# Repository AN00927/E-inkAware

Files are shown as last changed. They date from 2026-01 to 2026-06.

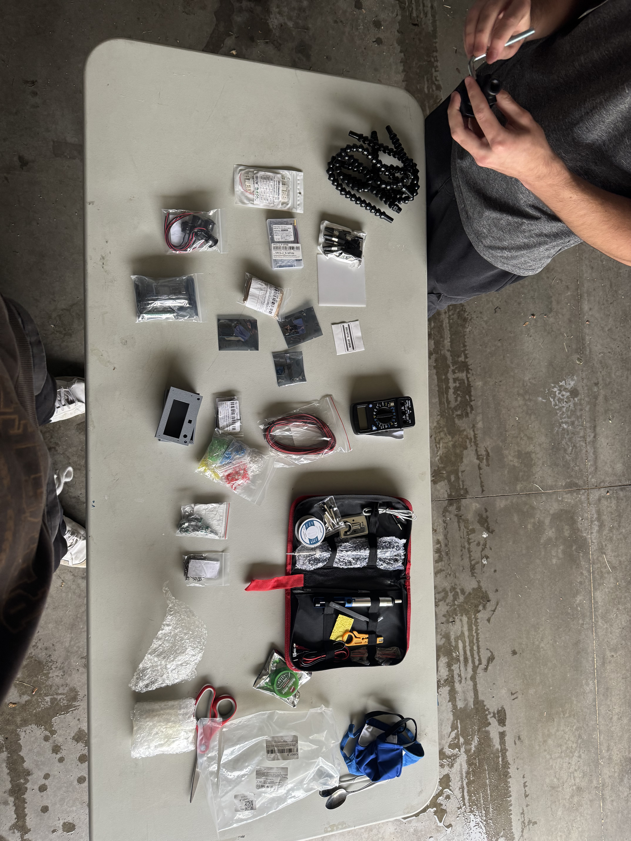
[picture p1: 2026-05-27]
Physical Progress Photos/MaterialsUnpacked.jpeg

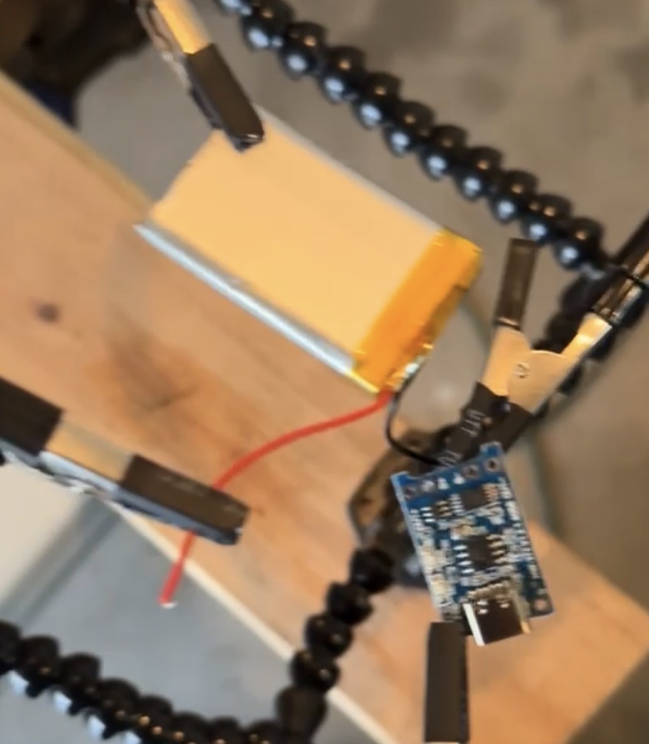
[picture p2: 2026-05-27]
Physical Progress Photos/InitialSolder.jpg

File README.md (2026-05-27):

# E-inkAware
I am creating a E-ink display that takes note of the light level around it to determine whether to turn on a reading light! The device is portable and will be display things like the time, calendar, and hopefully more complex things like real-time reminders. Progress is documented and explained at [HackClub](https://blueprint.hackclub.com/projects/8115)

In order to use it, you turn it on with the switch on the side. The display will show the current time and calendar. It will turn on the screen backlight based on the light level it senses. Use the rotary encoder to go between different pages! The pages are Dashboard, Notes, Note Viewer, and System info.
To add notes, long press the encoder button to turn on Bluetooth. Then connect to "EInk_Companion" from your phone or computer and send a message formatted as NOTE: "whatever note you have". Short press the encoder to open a note or toggle the frontlight manually. If you leave it alone for 30 minutes it'll go to sleep on its own. To wake it up press the encoder. It is charged by USB-C

A friend of mine and I made this project because we honestly thought it would be really cool to try to create our first project with a screen, since our previous projects have mostly been things that mankind could have made anytime in the last millenia (dehydrator)
We also wanted to expirement with light sensors since they are one of the cheapest yet most effective sensors
We will also make this over a 1-2 month period, and we'll make sure to document all of our progress.
We did not design a custom PCB. 
This design was reviewed by Justin Blevins.

In order to connect the electrical components, we will solder wires.

## Render
E-ink 3D Render

## Schematic
Schematic
" />

## Bill of Materials
| Product Name | Description | Project usage | Unit Price | Quantity | Total | Link |
|---|---|---|---|---|---|---|
| 2.9” SPI E-Ink Display | Low-power monochrome e-ink display using SPI | Displays persistent info; power only on refresh and/or partial refresh | $10.95 | 1 | $10.95 | https://www.aliexpress.us/item/3256804458201128.html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 |
| ESP32 DevKit / ESP32-WROOM-32 | 32-bit microcontroller | Main controller for display, sensors, power, and sleep | $6.03 | 1 | $6.03 | https://a.aliexpress.com/_mP8xeeh |
| BH1750 Ambient Light Sensor | Digital I²C light sensor | Auto front - light enable/adjust | $1.55 | 1 | $1.55 | https://a.aliexpress.com/_m0emckz |
| EC11 Rotary Encoder | Mechanical encoder + button | User input / navigation | $3.20 | 1 | $3.20 | https://a.aliexpress.com/_mMVUzI9 |
| White LEDs | Discrete white LEDs (2), voltage = 1.8, 3mm | Front-lighting in low light | $2.66 | 1 | $2.66 | https://a.aliexpress.com/_mP2d4oz |
| Logic-Level N-MOSFET (AO3400) | Low-side switch | PWM LED brightness control | $1.60 | 1 | $1.60 | https://a.aliexpress.com/_msAeC4N |
| Resistors (assorted) | 100kΩ | LED current limiting / tuning, and voltage divider for battery | $2.74 | 2 | $5.48 | https://a.aliexpress.com/_mK8bSHP |
| 1.4mm Frosted Acrylic / PET | Diffusing sheet | Even light spread | $4.04 | 1 | $4.04 | https://a.aliexpress.com/_mMZ5c1P |
| Li-Po Battery | 3.7V rechargeable battery 2 count, 1000mAh | Primary power storage | $5.24 | 1 | $5.24 | https://a.aliexpress.com/_msZFe1j |
| TP4056 Charging Module | Li-Po charger + protection | Safe charging | $6.07 | 1 | $6.07 | https://a.aliexpress.com/_mqVssZB |
| Wires (22 AWG, 5M) | Insulated copper wire | Interconnections | $3.05 | 1 | $3.05 | https://a.aliexpress.com/_msOwZ8D |
| Slide switch | Mechanical on/off switch | Hard power cutoff | $3.17 | 1 | $3.17 | https://www.aliexpress.us/item/3256806912505731.html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 |
| M2.6 Self-tapping Screws | Metric fasteners | Secure PCB & enclosure | $1.66 | 1 | $1.66 | https://www.aliexpress.us/item/2255800795894953.html |
| Decoupling Capacitors | 100nF cermaic decoupling  (805) | Power stabilization near the ESP32 and Display | $3.40 | 1 | $3.40 | https://a.aliexpress.com/_msBwDKz |

Subtotal: $54.70

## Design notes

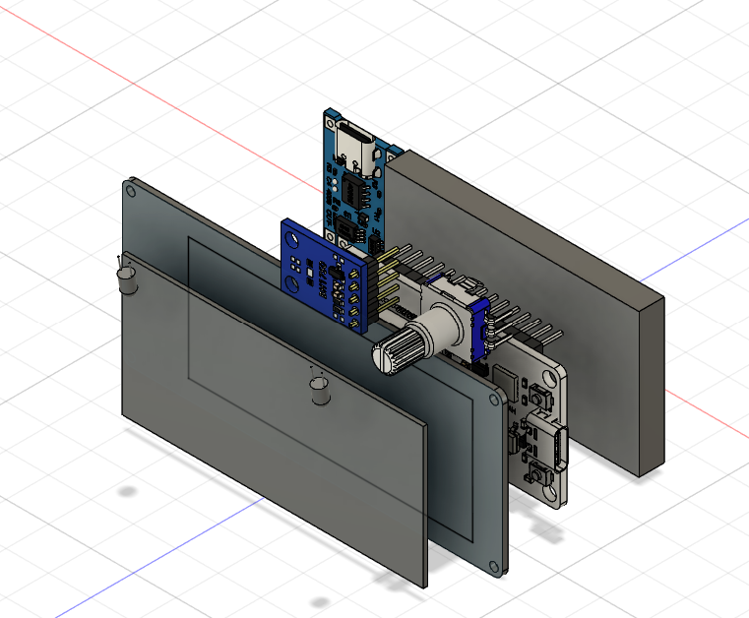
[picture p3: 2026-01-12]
Design Progress Photos/Screenshot 2025-12-28 181926.png

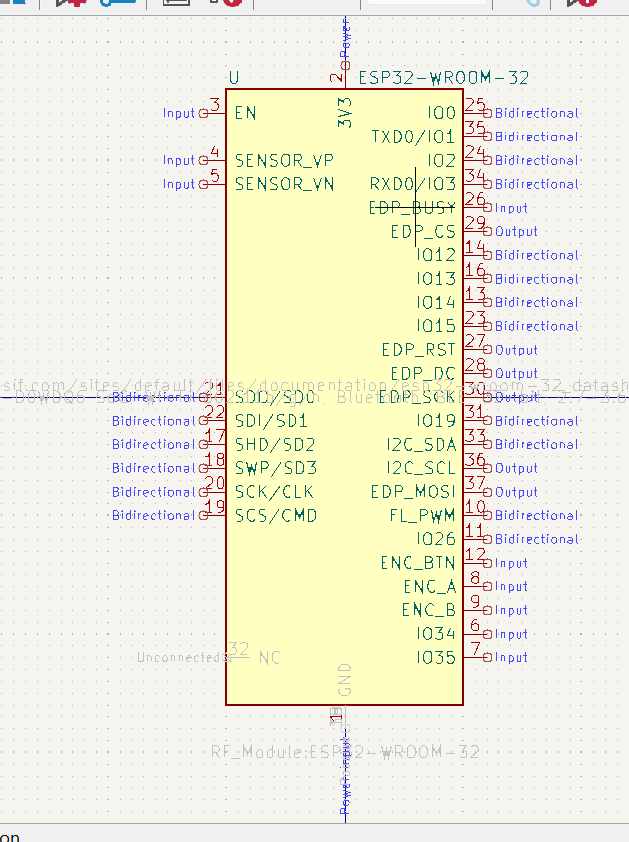
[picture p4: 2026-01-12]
Design Progress Photos/Screenshot 2026-01-08 215834.png

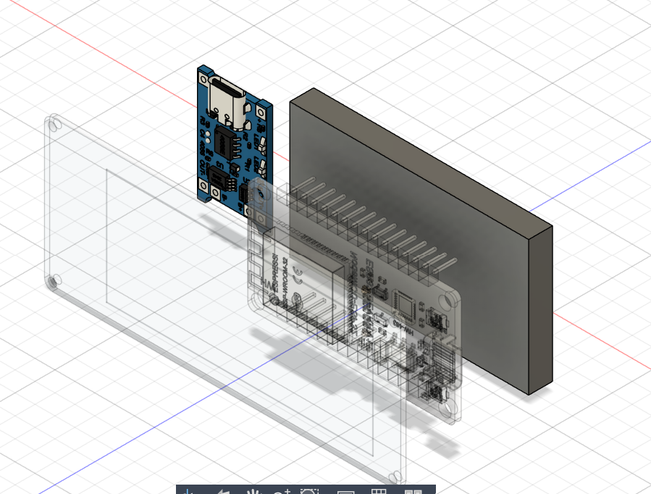
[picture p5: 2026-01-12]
Design Progress Photos/Screenshot 2025-12-28 150306.png

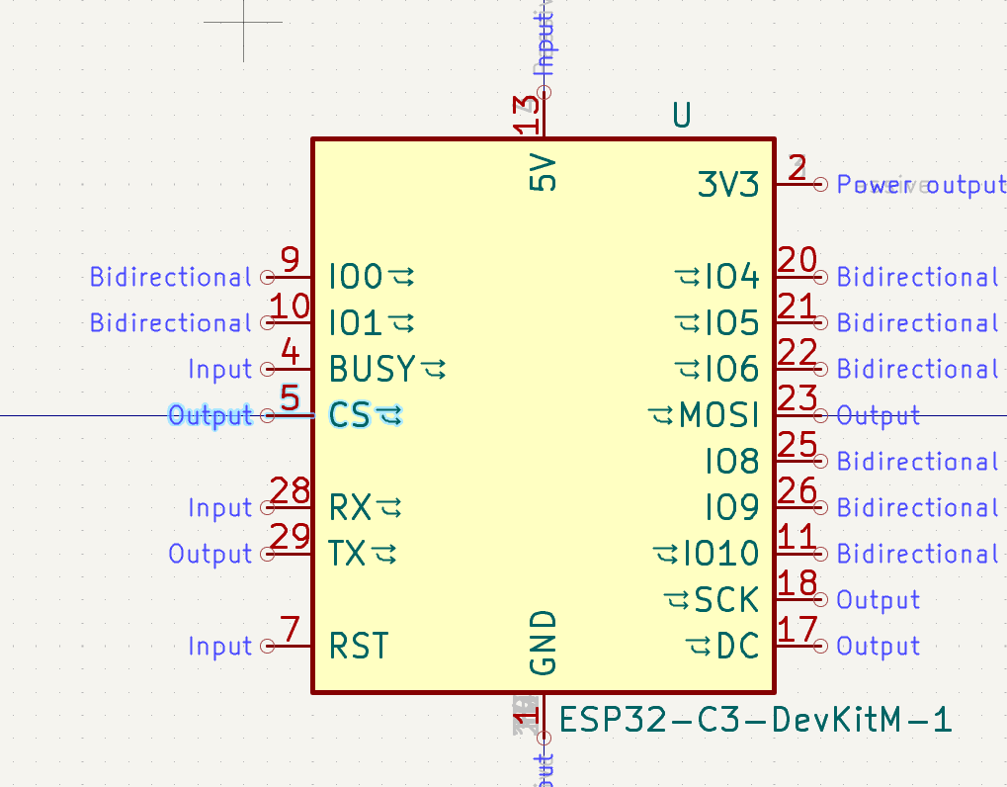
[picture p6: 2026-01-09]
Design Progress Photos/Screenshot 2026-01-07 214725.png

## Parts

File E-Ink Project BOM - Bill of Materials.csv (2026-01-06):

Product Name | Description | Project usage | Unit Price | Quantityy | Total | Link
2.9” SPI E-Ink Display | Low-power monochrome e-ink display using SPI | Displays persistent info; power only on refresh and/or partial refresh | $11.22 | 1 | $11.22 | https://a.aliexpress.com/_msPID7J
ESP32 DevKit / ESP32-WROOM-32 | 32-bit microcontroller | Main controller for display, sensors, power, and sleep | $6.24 | 1 | $6.24 | https://a.aliexpress.com/_mP8xeeh
BH1750 Ambient Light Sensor | Digital I²C light sensor | Auto front - light enable/adjust | $2.39 | 1 | $2.39 | https://a.aliexpress.com/_m0emckz
EC11 Rotary Encoder | Mechanical encoder + button | User input / navigation | $3.27 | 1 | $3.27 | https://a.aliexpress.com/_mMVUzI9
White LEDs | Discrete white LEDs | Front-lighting in low light | $2.71 | 1 | $2.71 | https://a.aliexpress.com/_mP2d4oz
Logic-Level N-MOSFET (AO3400) | Low-side switch | PWM LED brightness control | $1.64 | 1 | $1.64 | https://a.aliexpress.com/_msAeC4N
Resistors (assorted) | Fixed-value resistors | LED current limiting / tuning | $2.70 | 2 | $5.40 | https://a.aliexpress.com/_mK8bSHP
1.4mm Frosted Acrylic / PET | Diffusing sheet | Even light spread | $4.44 | 1 | $4.44 | https://a.aliexpress.com/_mMZ5c1P
Li-Po Battery | 3.7V rechargeable battery | Primary power storage | $4.51 | 1 | $4.51 | https://a.aliexpress.com/_mKdA6tn
TP4056 Charging Module | Li-Po charger + protection | Safe charging | $6.47 | 1 | $6.47 | https://a.aliexpress.com/_mqVssZB
Wires (22 AWG) | Insulated copper wire | Interconnections | $3.08 | 1 | $3.08 | https://a.aliexpress.com/_msOwZ8D
Slide switch | Mechanical on/off switch | Hard power cutoff | $2.81 | 1 | $2.81 | https://www.aliexpress.us/item/3256806912505731.html?curPageLogUid=DC3gG5h1SoYY
Custom 3D-Printed Enclosure | CAD-designed encolsure | Physical protection & layout | $5.00 | 1 | $5.00 | I will print
M2.5 Self-tapping Screws | Metric fasteners | Secure PCB & enclosure | $1.76 | 1 | $1.76 | https://www.aliexpress.us/item/2255800795894953.html
 |  |  |  | Subtotal | $64.25
 |  |  |  | Discount | $50.23
 | Contingency (price changes / flawed parts) |  |  | 15% | $57.76

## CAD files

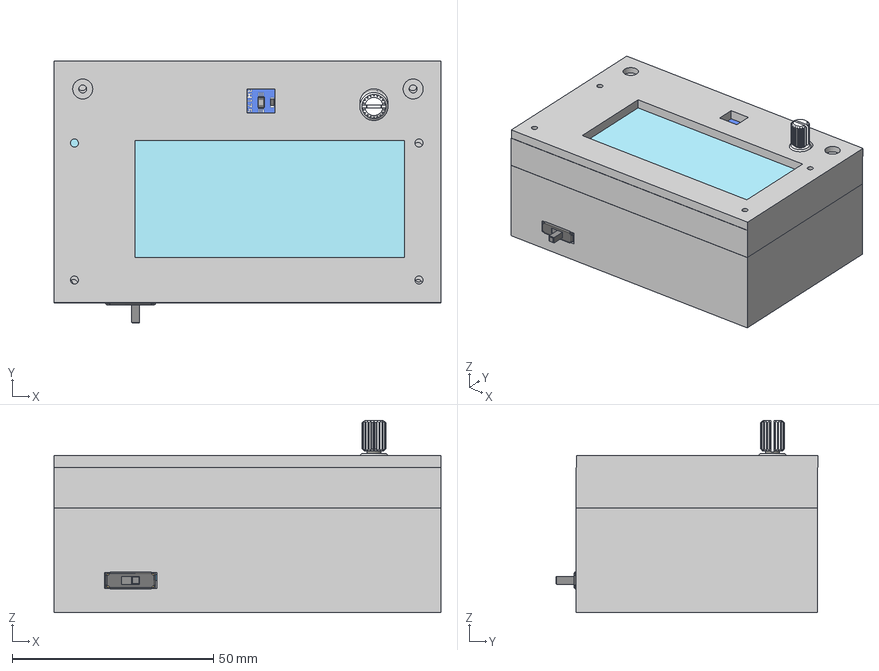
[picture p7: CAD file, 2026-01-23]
CAD Files/E-ink project STEP File.step
96.0 x 65.1 x 47.7 mm
E-ink display
rotary Encoder
LED1
LED2
Diffuser
Light Sensor
LiPo Battery
ESP32
Slide Switch
MOSFET (AO3400, not A1SHB)
TP4056

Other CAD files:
CAD Files/E-ink project.f3z

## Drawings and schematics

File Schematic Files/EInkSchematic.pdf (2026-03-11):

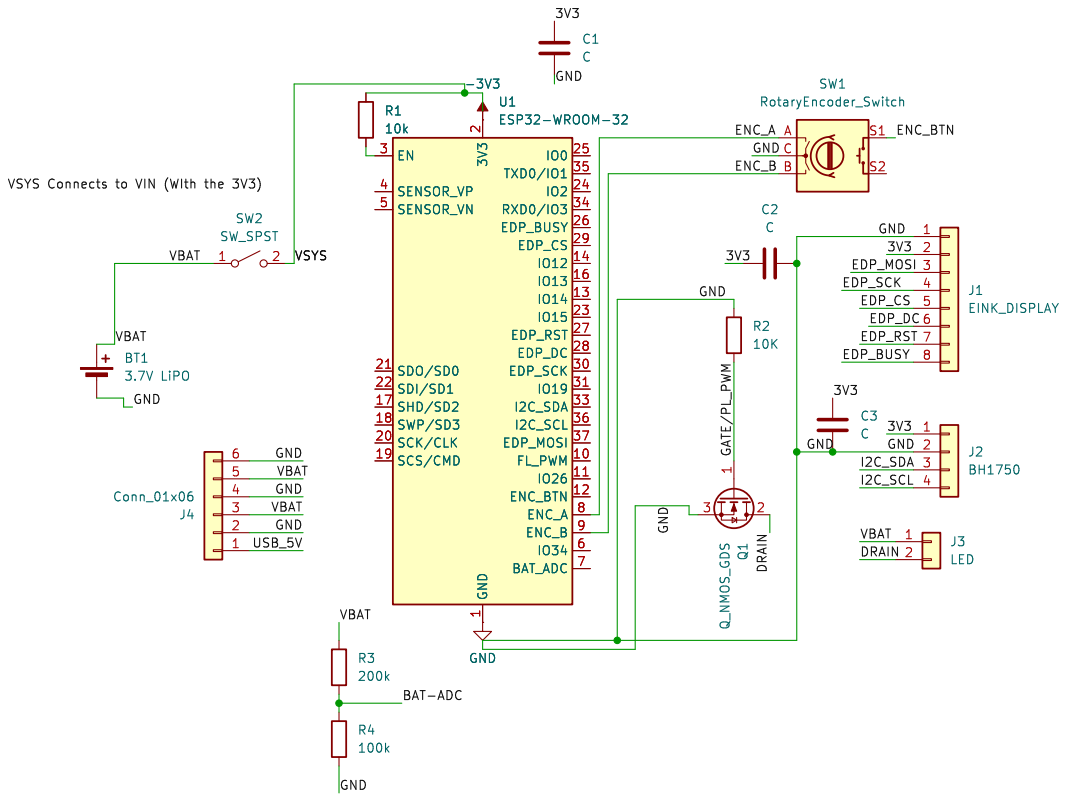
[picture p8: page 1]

Id: 1/1 Title: File: light-aware-eink.kicad_sch Sheet: /

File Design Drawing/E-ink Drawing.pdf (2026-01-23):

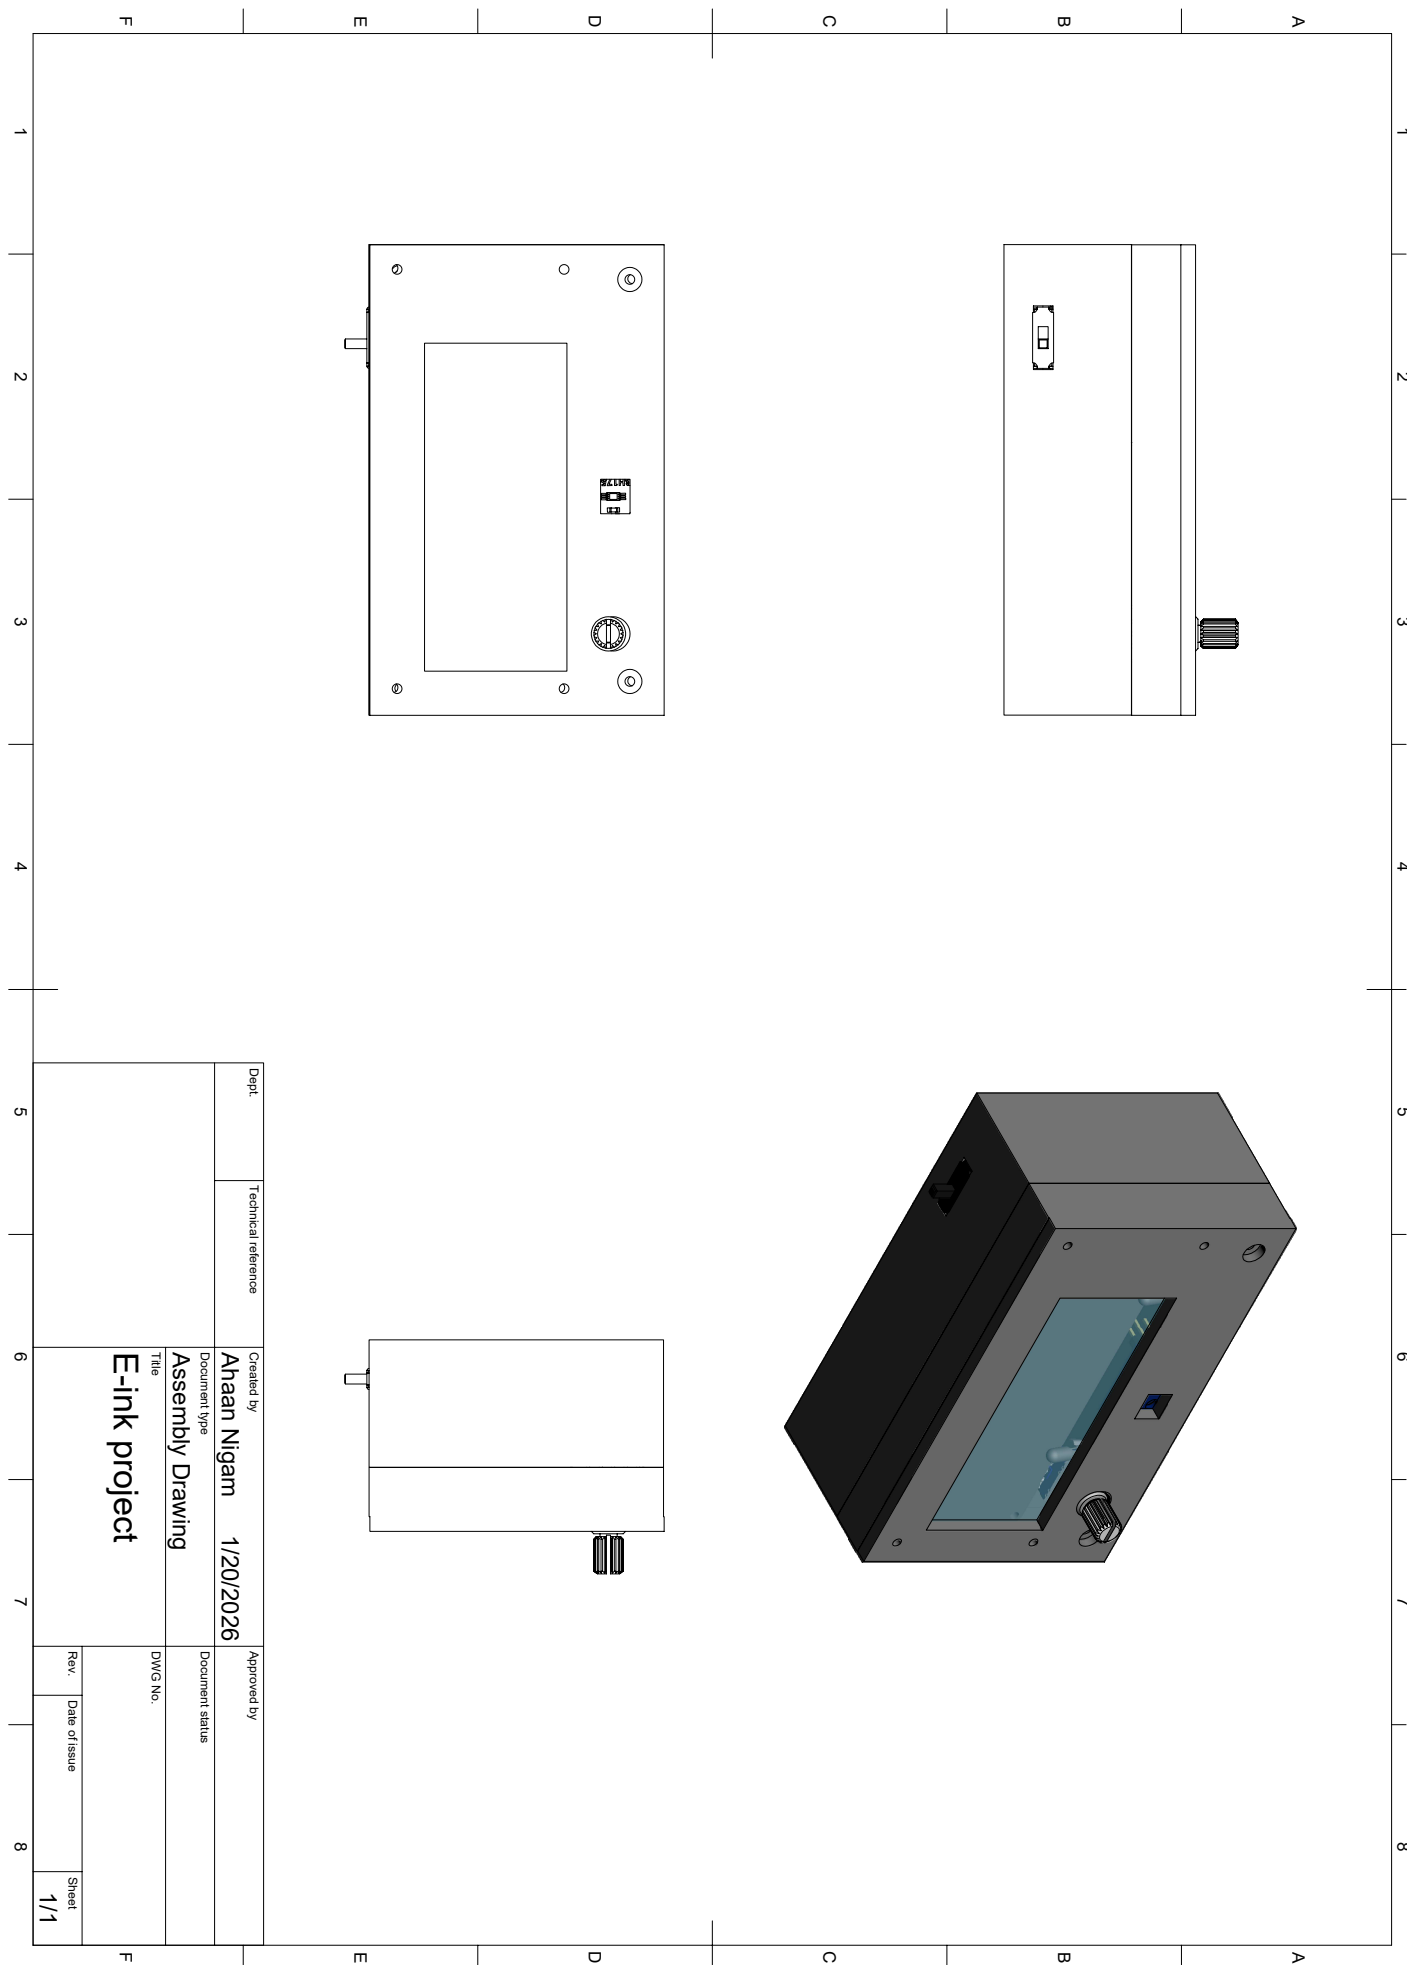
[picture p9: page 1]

1 A 2 3 4 5 6 7 8 1 2 3 4 5 6 7 8 FEDCB FEDCBA Dept. Technical reference Created by Approved by Title DWG No. Document type Document status Rev. Date of issue Sheet Assembly Drawing1/20/2026 1/1 E-ink project Ahaan Nigam

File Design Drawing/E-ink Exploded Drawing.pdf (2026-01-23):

29.05 66.89

# 13 ⁸⁷.45

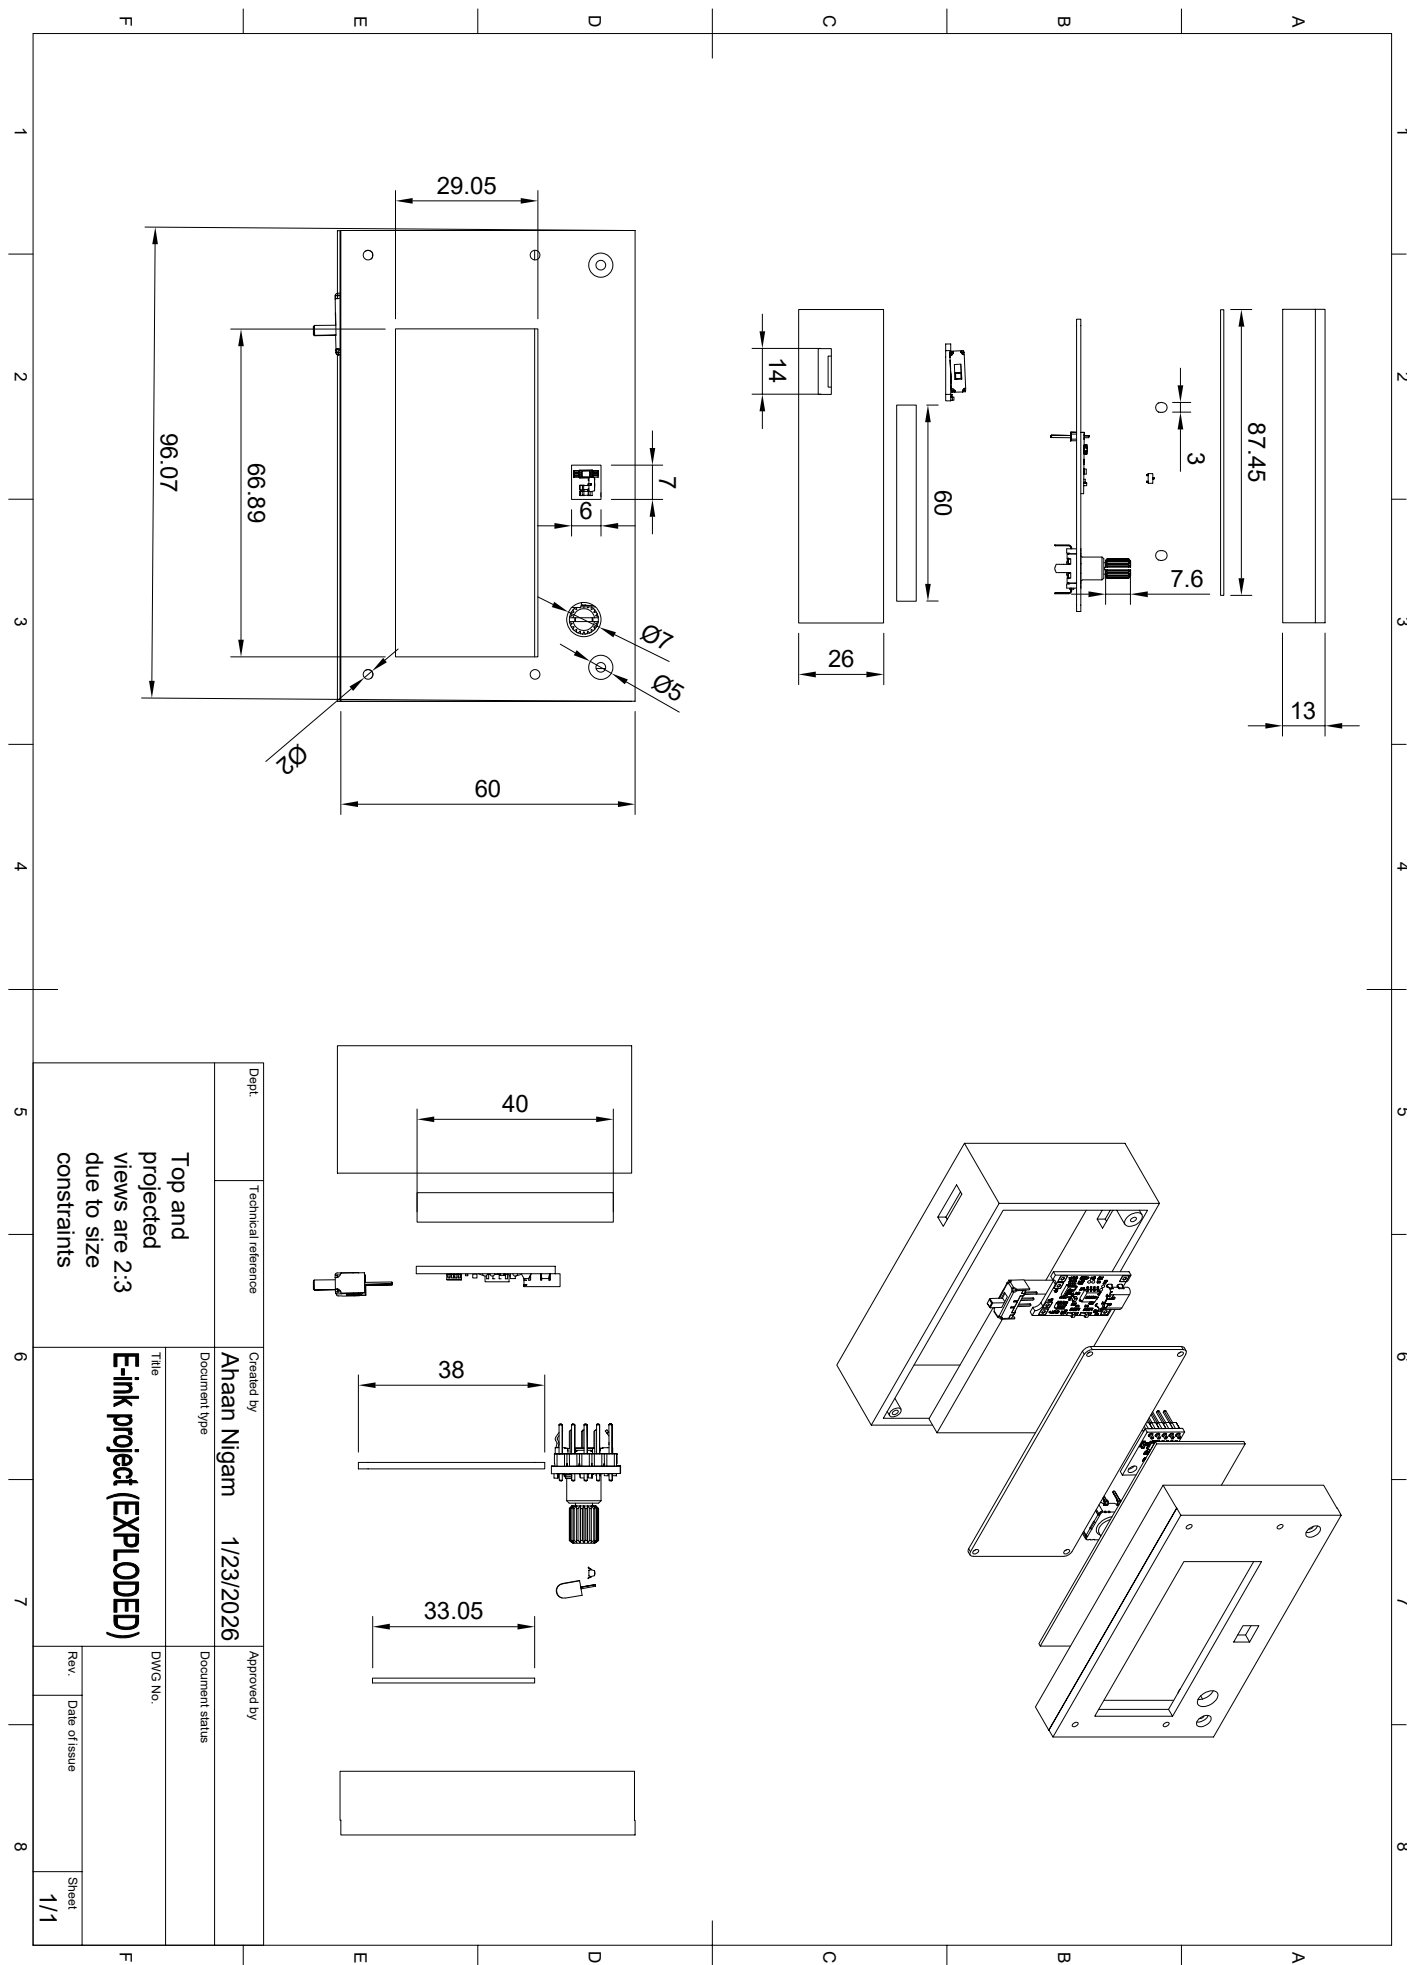
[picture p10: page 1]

1 A 2 3 4 5 6 7 8 1 2 3 4 5 6 7 8 FEDCB FEDCBA Dept. Technical reference Created by Approved by Title DWG No. Document type Document status Rev. Date of issue Sheet 1/23/2026 1/1 Ahaan Nigam constraints due to size views are 2:3 projected Top and 96.07

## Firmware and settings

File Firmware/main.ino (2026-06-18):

/*
  E-inkAware — WeAct 2.9" B/W (GxEPD2_BW)
  Fixed for ESP32 Arduino core 3.x
*/

#include <Arduino.h>
#include <Wire.h>
#include <Preferences.h>
#include <WiFi.h>
#include <time.h>

#include <FS.h>
#include <LittleFS.h>
#include <ArduinoOTA.h>

#include <BLEDevice.h>
#include <BLEUtils.h>
#include <BLEServer.h>
#include <BLE2902.h>

#include <BH1750.h>

#include <GxEPD2_BW.h>
#include <Adafruit_GFX.h>
#include <Fonts/FreeMonoBold9pt7b.h>

// ========== CONFIG ==========
#define EPD_CS   5
#define EPD_DC   17
#define EPD_RST  16
#define EPD_BUSY 4
#define EPD_SCK  18
#define EPD_MOSI 23

#define ENC_A_PIN     14
#define ENC_B_PIN     27
#define ENC_BTN_PIN   33

#define I2C_SDA       21
#define I2C_SCL       22

#define LED_PWM_PIN   25
// FIX: core 3.x uses pin-based LEDC, no channel needed
#define LEDC_FREQ     5000
#define LEDC_RES      8

#define BAT_ADC_PIN   35
const float DIVIDER_FACTOR = 3.0f;
const float BAT_EMPTY_V = 3.0f;
const float BAT_FULL_V  = 4.2f;

const uint32_t INACTIVITY_MIN = 30;

#define SERVICE_UUID   "e1230001-1234-5678-1234-56789abcdef0"
#define CHAR_TEXT_UUID "e1230002-1234-5678-1234-56789abcdef0"

static const char *PREF_NS         = "einkapp";
static const char *DEVICE_NAME     = "EInk_Companion";
static const int   MAX_NOTES       = 128;
static const int   NOTES_PER_PAGE  = 6;
static const int   NOTE_CHARS_PER_LINE = 38;
static const int   NOTE_VISIBLE_LINES  = 6;
static const char *NOTES_DIR       = "/notes";
static const char *NOTE_SEQ_KEY    = "note_seq";
static const char *WIFI_SSID_KEY   = "ssid";
static const char *WIFI_PASS_KEY   = "pass";
static const char *LIGHT_MODE_KEY  = "light_mode";

enum PageMode : uint8_t {
  PAGE_DASHBOARD = 0,
  PAGE_NOTES     = 1,
  PAGE_NOTE_VIEW = 2,
  PAGE_SYSTEM    = 3,
  PAGE_OTA       = 4,
};

enum LightMode : uint8_t {
  LIGHT_MODE_AUTO       = 0,
  LIGHT_MODE_FORCED_ON  = 1,
  LIGHT_MODE_FORCED_OFF = 2,
};

GxEPD2_BW<GxEPD2_290_BS, GxEPD2_290_BS::HEIGHT> display(
  GxEPD2_290_BS(EPD_CS, EPD_DC, EPD_RST, EPD_BUSY));

BH1750     lightMeter;
Preferences prefs;

// BLE
BLEServer         *bleServer   = nullptr;
BLECharacteristic *textChar    = nullptr;
bool               bleEnabled  = false;
unsigned long      bleEnableTs = 0;
const unsigned long BLE_ENABLE_TIMEOUT_MS = 2UL * 60UL * 1000UL;

// WiFi / OTA
bool          wifiConnected = false;
bool          otaActive     = false;
unsigned long otaStartTs    = 0;
const unsigned long OTA_ENABLE_TIMEOUT_MS = 20UL * 60UL * 1000UL;

// UI
PageMode currentPage       = PAGE_DASHBOARD;
int      selectedNoteIndex = 0;
int      noteViewIndex     = 0;
int      notesPageOffset   = 0;
int      noteScrollLine    = 0;


// Encoder
static portMUX_TYPE encoderMux = portMUX_INITIALIZER_UNLOCKED;  // ADD THIS
volatile int32_t encoderDelta     = 0;
volatile uint8_t encoderLastState = 0;
int32_t          encoderAccum     = 0;

// Front-light
const float LUX_THRESHOLD_ON  = 40.0f;
const float LUX_THRESHOLD_OFF = 55.0f;
const int   LIGHT_PWM_ON      = 200;
const int   LIGHT_PWM_MIN     = 0;
LightMode   lightMode         = LIGHT_MODE_AUTO;
bool        frontLightOn      = false;
unsigned long lastLightSampleMs = 0;

// Notes index
String   noteFiles[MAX_NOTES];
int      noteCount    = 0;
uint32_t nextNoteSeq  = 1;
bool     filesystemReady = false;

// Timing
unsigned long lastActivityMs         = 0;
unsigned long lastDashboardRefreshMs = 0;
unsigned long lastSystemRefreshMs    = 0;
unsigned long lastOtaRefreshMs       = 0;

// ========== HELPERS ==========
int batteryPercentFromVoltage(float v) {
  if (v <= BAT_EMPTY_V) return 0;
  if (v >= BAT_FULL_V)  return 100;
  return (int)round((v - BAT_EMPTY_V) / (BAT_FULL_V - BAT_EMPTY_V) * 100.0f);
}

float readBatteryVoltage() {
  uint16_t raw = analogRead(BAT_ADC_PIN);
  return (raw / 4095.0f) * 3.3f * DIVIDER_FACTOR;
}

String normalizeNoteText(String text) {
  text.replace("\r", " ");
  text.replace("\n", " ");
  text.replace("\t", " ");
  text.trim();
  return text;
}

String notePathForSeq(uint32_t seq) {
  char path[48];
  snprintf(path, sizeof(path), "%s/note_%08lu.txt", NOTES_DIR, (unsigned long)seq);
  return String(path);
}

String readFileText(const String &path) {
  File file = LittleFS.open(path, FILE_READ);
  if (!file) return "";
  String text = file.readString();
  file.close();
  return text;
}

String notePreviewFromText(String text) {
  text = normalizeNoteText(text);
  if (text.length() <= 32) return text;
  return text.substring(0, 29) + "...";
}

String currentLightModeLabel() {
  switch (lightMode) {
    case LIGHT_MODE_FORCED_ON:  return "ON";
    case LIGHT_MODE_FORCED_OFF: return "OFF";
    default:                    return "AUTO";
  }
}

String currentTimeLabel() {
  struct tm timeinfo;
  if (!getLocalTime(&timeinfo)) return "No Time";
  char buf[32];
  strftime(buf, sizeof(buf), "%H:%M", &timeinfo);
  return String(buf);
}

String currentDateLabel() {
  struct tm timeinfo;
  if (!getLocalTime(&timeinfo)) return "";
  char buf[32];
  strftime(buf, sizeof(buf), "%a %d %b", &timeinfo);
  return String(buf);
}

String uptimeLabel() {
  uint32_t seconds = millis() / 1000UL;
  uint32_t minutes = seconds / 60UL;
  uint32_t hours   = minutes / 60UL;
  minutes %= 60UL;
  seconds %= 60UL;
  char buf[32];
  snprintf(buf, sizeof(buf), "%luh %lum %lus",
    (unsigned long)hours, (unsigned long)minutes, (unsigned long)seconds);
  return String(buf);
}

String bytesLabel(uint32_t bytes) {
  if (bytes >= 1024UL * 1024UL) {
    char buf[24];
    snprintf(buf, sizeof(buf), "%.1f MB", bytes / 1024.0f / 1024.0f);
    return String(buf);
  }
  if (bytes >= 1024UL) {
    char buf[24];
    snprintf(buf, sizeof(buf), "%.1f KB", bytes / 1024.0f);
    return String(buf);
  }
  return String(bytes) + " B";
}

void drawFrame(const String &title, const String &subtitle = "") {
  display.setFont(&FreeMonoBold9pt7b);
  display.setTextColor(GxEPD_BLACK);
  display.setTextSize(1);
  display.setCursor(8, 12);
  display.print(title);
  if (subtitle.length() > 0) {
    display.setCursor(170, 12);
    display.print(subtitle);
  }
  display.setFont(nullptr);
  display.drawFastHLine(0, 16, 296, GxEPD_BLACK);
}

void drawFooter(const String &text) {
  display.drawFastHLine(0, 116, 296, GxEPD_BLACK);
  display.setFont(nullptr);
  display.setTextSize(1);
  display.setTextColor(GxEPD_BLACK);
  display.setCursor(8, 126);
  display.print(text);
}

// ========== FILESYSTEM ==========
void ensureFilesystems() {
  if (!filesystemReady) filesystemReady = LittleFS.begin(true);
  if (!filesystemReady) return;
  if (!LittleFS.exists(NOTES_DIR)) LittleFS.mkdir(NOTES_DIR);
  nextNoteSeq = prefs.getUInt(NOTE_SEQ_KEY, 1);
  lightMode   = (LightMode)prefs.getUChar(LIGHT_MODE_KEY, LIGHT_MODE_AUTO);
}

void refreshNotesIndex() {
  noteCount = 0;
  if (!filesystemReady) return;
  File root = LittleFS.open(NOTES_DIR);
  if (!root || !root.isDirectory()) return;
  // AFTER
  for (File file = root.openNextFile(); file && noteCount < MAX_NOTES; file = root.openNextFile()) {
    if (file.isDirectory()) { file.close(); continue; }
    String path = String(file.name());
    if (!path.startsWith("/")) path = String(NOTES_DIR) + "/" + path;
    noteFiles[noteCount++] = path;
    file.close();
  }
  root.close();
  for (int i = 0; i < noteCount - 1; ++i) {
    for (int j = i + 1; j < noteCount; ++j) {
      if (noteFiles[j].compareTo(noteFiles[i]) < 0) {
        String tmp   = noteFiles[i];
        noteFiles[i] = noteFiles[j];
        noteFiles[j] = tmp;
      }
    }
  }
  if (noteCount == 0) { selectedNoteIndex = 0; noteViewIndex = 0; notesPageOffset = 0; noteScrollLine = 0; return; }
  if (selectedNoteIndex >= noteCount) selectedNoteIndex = noteCount - 1;
  if (selectedNoteIndex < 0)          selectedNoteIndex = 0;
  if (noteViewIndex >= noteCount)     noteViewIndex = noteCount - 1;
  if (noteViewIndex < 0)              noteViewIndex = 0;
  if (notesPageOffset > selectedNoteIndex)
    notesPageOffset = (selectedNoteIndex / NOTES_PER_PAGE) * NOTES_PER_PAGE;
  if (notesPageOffset < 0) notesPageOffset = 0;
}

int    loadNotesCount() { return noteCount; }
String readNote(int idx) { if (idx < 0 || idx >= noteCount) return ""; return readFileText(noteFiles[idx]); }

bool deleteNote(int idx) {
  if (idx < 0 || idx >= noteCount) return false;
  bool removed = LittleFS.remove(noteFiles[idx]);
  refreshNotesIndex();
  return removed;
}

void clearAllNotes() {
  if (!filesystemReady) return;
  for (int i = 0; i < noteCount; ++i) LittleFS.remove(noteFiles[i]);
  refreshNotesIndex();
}

bool addNote(const String &text) {
  if (!filesystemReady) ensureFilesystems();
  if (!filesystemReady) return false;
  if (noteCount >= MAX_NOTES) { LittleFS.remove(noteFiles[0]); refreshNotesIndex(); }
  String noteText = normalizeNoteText(text);
  if (noteText.length() == 0) return false;
  String path = notePathForSeq(nextNoteSeq++);
  File file = LittleFS.open(path, FILE_WRITE);
  if (!file) return false;
  file.print(noteText);
  file.close();
  prefs.putUInt(NOTE_SEQ_KEY, nextNoteSeq);
  refreshNotesIndex();
  return true;
}

// ========== WIFI / NTP ==========
void storeWiFiCredentials(const String &ssid, const String &pass) {
  prefs.putString(WIFI_SSID_KEY, ssid);
  prefs.putString(WIFI_PASS_KEY, pass);
}

bool loadWiFiCredentials(String &ssid, String &pass) {
  ssid = prefs.getString(WIFI_SSID_KEY, "");
  pass = prefs.getString(WIFI_PASS_KEY, "");
  return ssid.length() > 0;
}

bool connectWiFiForServices(uint32_t timeoutMs = 15000UL) {
  String ssid, pass;
  if (!loadWiFiCredentials(ssid, pass)) return false;
  if (WiFi.status() == WL_CONNECTED) { wifiConnected = true; return true; }
  WiFi.persistent(false);
  WiFi.mode(WIFI_STA);
  WiFi.setSleep(true);
  WiFi.begin(ssid.c_str(), pass.c_str());
  unsigned long start = millis();
  while (millis() - start < timeoutMs) {
    if (WiFi.status() == WL_CONNECTED) { wifiConnected = true; return true; }
    delay(100);
  }
  WiFi.disconnect(true, true);
  WiFi.mode(WIFI_OFF);
  wifiConnected = false;
  return false;
}

void disconnectWiFi() {
  if (WiFi.status() == WL_CONNECTED) WiFi.disconnect(true, true);
  WiFi.mode(WIFI_OFF);
  wifiConnected = false;
}

bool syncTimeFromNTP() {
  if (!connectWiFiForServices()) return false;
  configTime(0, 0, "pool.ntp.org", "time.nist.gov");
  struct tm timeinfo;
  bool ok = getLocalTime(&timeinfo, 5000);
  if (!otaActive) disconnectWiFi();
  return ok;
}

// ========== LIGHT ==========
void setLightMode(LightMode mode) {
  lightMode = mode;
  prefs.putUChar(LIGHT_MODE_KEY, (uint8_t)lightMode);
}

void setFrontLight(bool on) {
  if (frontLightOn == on) return;
  frontLightOn = on;
  // FIX: core 3.x uses ledcWrite(pin, duty) not ledcWrite(channel, duty)
  ledcWrite(LED_PWM_PIN, on ? LIGHT_PWM_ON : LIGHT_PWM_MIN);
}

void toggleLightMode() {
  switch (lightMode) {
    case LIGHT_MODE_AUTO:       setLightMode(LIGHT_MODE_FORCED_ON);  setFrontLight(true);  break;
    case LIGHT_MODE_FORCED_ON:  setLightMode(LIGHT_MODE_FORCED_OFF); setFrontLight(false); break;
    default:                    setLightMode(LIGHT_MODE_AUTO); break;
  }
}

void autoAdjustLight() {
  if (millis() - lastLightSampleMs < 1000) return;
  lastLightSampleMs = millis();
  switch (lightMode) {
    case LIGHT_MODE_FORCED_ON:  setFrontLight(true);  return;
    case LIGHT_MODE_FORCED_OFF: setFrontLight(false); return;
    default: break;
  }
  float lux = lightMeter.readLightLevel();
  if (lux < 0) return; 
  if (!frontLightOn && lux < LUX_THRESHOLD_ON)   setFrontLight(true);
  else if (frontLightOn && lux > LUX_THRESHOLD_OFF) setFrontLight(false);
}

// ========== PAGE ROUTING ==========
PageMode cycleMainPage(PageMode page, int step) {
  const PageMode cycle[] = {PAGE_DASHBOARD, PAGE_NOTES, PAGE_SYSTEM, PAGE_OTA};
  int index = 0;
  for (int i = 0; i < 4; i++) { if (cycle[i] == page) { index = i; break; } }
  index = ((index + step) % 4 + 4) % 4;
  return cycle[index];
}

// Forward declarations
void drawDashboard();
void drawNotesList();
void drawNote(int idx);
void drawSystem();
void drawOtaPage();
void drawCurrentPage();
void bleStop();
bool startOtaSession();
void stopOtaSession();

// ========== DRAW FUNCTIONS ==========
void drawDashboard() {
  display.setRotation(1);
  display.setFullWindow();
  display.firstPage();
  do {
    display.fillScreen(GxEPD_WHITE);
    drawFrame("Dashboard", bleEnabled ? "BLE on" : "");
    display.setFont(&FreeMonoBold9pt7b);
    display.setTextColor(GxEPD_BLACK);
    display.setTextSize(2);
    display.setCursor(8, 48);
    display.print(currentTimeLabel());
    display.setTextSize(1);
    display.setCursor(168, 34);
    String dateLabel = currentDateLabel();
    display.print(dateLabel.length() > 0 ? dateLabel : "No date");
    display.setFont(nullptr);
    display.setTextSize(1);
    float vb  = readBatteryVoltage();
    int   pct = batteryPercentFromVoltage(vb);
    display.setCursor(8, 72);
    display.printf("Battery: %.2fV (%d%%)", vb, pct);
    display.setCursor(8, 84);
    display.printf("Notes: %d  Light: %s", loadNotesCount(), currentLightModeLabel().c_str());
    display.setCursor(8, 96);
    if (noteCount > 0) {
      String preview = notePreviewFromText(readNote(noteCount - 1));
      display.print("Latest: ");
      display.print(preview.length() > 0 ? preview : "(empty)");
    } else {
      display.print("No notes stored");
    }
    drawFooter("Short:light  Long:BLE  Turn:pages");
  } while (display.nextPage());
  display.hibernate();
  lastDashboardRefreshMs = millis();
}

void drawNotesList() {
  display.setRotation(1);
  display.setFullWindow();
  display.firstPage();
  do {
    display.fillScreen(GxEPD_WHITE);
    drawFrame("Notes", String(loadNotesCount()) + " stored");
    display.setFont(nullptr);
    display.setTextSize(1);
    if (noteCount == 0) {
      display.setTextColor(GxEPD_BLACK);
      display.setCursor(8, 44);
      display.print("No notes yet.");
      display.setCursor(8, 58);
      display.print("Send NOTE:... over BLE.");
      drawFooter("Long:BLE  Turn:pages");
    } else {
      if (notesPageOffset > selectedNoteIndex)
        notesPageOffset = (selectedNoteIndex / NOTES_PER_PAGE) * NOTES_PER_PAGE;
      int endIndex = min(noteCount, notesPageOffset + NOTES_PER_PAGE);
      for (int i = notesPageOffset; i < endIndex; ++i) {
        int row  = i - notesPageOffset;
        int y    = 32 + row * 14;
        bool sel = (i == selectedNoteIndex);
        if (sel) { display.fillRect(6, y - 10, 284, 13, GxEPD_BLACK); display.setTextColor(GxEPD_WHITE); }
        else      { display.setTextColor(GxEPD_BLACK); }
        display.setCursor(10, y);
        display.printf("%d. ", i + 1);
        String preview = notePreviewFromText(readNote(i));
        display.print(preview.length() > 0 ? preview : "(empty)");
      }
      int totalPages = (noteCount + NOTES_PER_PAGE - 1) / NOTES_PER_PAGE;
      int pageNumber = (selectedNoteIndex / NOTES_PER_PAGE) + 1;
      drawFooter("Short:open  Long:BLE  Pg " + String(pageNumber) + "/" + String(totalPages));
    }
  } while (display.nextPage());
  display.hibernate();
}

void drawNote(int idx) {
  String text = readNote(idx);
  if (text.length() == 0) text = "(empty note)";
  int totalLines = max(1, ((int)text.length() + NOTE_CHARS_PER_LINE - 1) / NOTE_CHARS_PER_LINE);
  if (noteScrollLine < 0) noteScrollLine = 0;
  if (noteScrollLine > max(0, totalLines - NOTE_VISIBLE_LINES))
    noteScrollLine = max(0, totalLines - NOTE_VISIBLE_LINES);
  display.setRotation(1);
  display.setFullWindow();
  display.firstPage();
  do {
    display.fillScreen(GxEPD_WHITE);
    drawFrame("Note " + String(idx + 1), String(noteScrollLine + 1) + "/" + String(totalLines));
    display.setFont(nullptr);
    display.setTextSize(1);
    display.setTextColor(GxEPD_BLACK);
    int lineY = 32;
    for (int line = 0; line < NOTE_VISIBLE_LINES; ++line) {
      int sourceLine = noteScrollLine + line;
      if (sourceLine >= totalLines) break;
      int start = sourceLine * NOTE_CHARS_PER_LINE;
      int end   = min(start + NOTE_CHARS_PER_LINE, (int)text.length());
      display.setCursor(8, lineY);
      display.print(text.substring(start, end));
      lineY += 12;
    }
    drawFooter("Short:back  Long:delete  Turn:scroll");
  } while (display.nextPage());
  display.hibernate();
}

void drawSystem() {
  display.setRotation(1);
  display.setFullWindow();
  display.firstPage();
  do {
    display.fillScreen(GxEPD_WHITE);
    drawFrame("System", uptimeLabel());
    display.setFont(nullptr);
    display.setTextSize(1);
    display.setTextColor(GxEPD_BLACK);
    display.setCursor(8, 30);  display.printf("Notes: %d", loadNotesCount());
    display.setCursor(8, 42);  display.printf("BLE: %s  OTA: %s", bleEnabled ? "on" : "off", otaActive ? "on" : "off");
    display.setCursor(8, 54);  display.printf("WiFi: %s  Light: %s", wifiConnected ? "on" : "off", currentLightModeLabel().c_str());
    display.setCursor(8, 66);  display.printf("Heap: %u", (unsigned)ESP.getFreeHeap());
    display.setCursor(8, 78);  display.printf("FS: %s", filesystemReady ? "ready" : "error");
    if (filesystemReady) {
      display.setCursor(8, 90);
      display.printf("Storage: %s / %s",
        bytesLabel(LittleFS.usedBytes()).c_str(),
        bytesLabel(LittleFS.totalBytes()).c_str());
    }
    drawFooter("Short:OTA  Long:BLE  Turn:pages");
  } while (display.nextPage());
  display.hibernate();
  lastSystemRefreshMs = millis();
}

void drawOtaPage() {
  display.setRotation(1);
  display.setFullWindow();
  display.firstPage();
  do {
    display.fillScreen(GxEPD_WHITE);
    drawFrame("OTA", otaActive ? "ready" : "idle");
    display.setFont(nullptr);
    display.setTextSize(1);
    display.setTextColor(GxEPD_BLACK);
    display.setCursor(8, 30);
    if (otaActive && WiFi.status() == WL_CONNECTED) {
      display.print("IP: "); display.print(WiFi.localIP().toString());
    } else {
      display.print("Need WiFi creds to use OTA.");
    }
    display.setCursor(8, 42); display.print("Hostname: "); display.print(DEVICE_NAME);
    display.setCursor(8, 54); display.print(otaActive ? "ArduinoOTA is live" : "BLE: WIFI:ssid|pass");
    display.setCursor(8, 66); display.print("Short: start/stop OTA");
    display.setCursor(8, 78); display.print("Keep device awake during upload.");
    drawFooter("Short:toggle  Long:BLE  Turn:pages");
  } while (display.nextPage());
  display.hibernate();
  lastOtaRefreshMs = millis();
}

void drawCurrentPage() {
  switch (currentPage) {
    case PAGE_DASHBOARD: drawDashboard();         break;
    case PAGE_NOTES:     drawNotesList();         break;
    case PAGE_NOTE_VIEW: drawNote(noteViewIndex); break;
    case PAGE_SYSTEM:    drawSystem();            break;
    case PAGE_OTA:       drawOtaPage();           break;
  }
}

// ========== OTA ==========
void setupOtaHandlers() {
  ArduinoOTA.setHostname(DEVICE_NAME);
  ArduinoOTA.onStart([]() { setFrontLight(false); display.hibernate(); });
  ArduinoOTA.onEnd([]()   { Serial.println("OTA complete"); });
  ArduinoOTA.onProgress([](unsigned int progress, unsigned int total) {
    Serial.printf("OTA: %u%%\r", (progress * 100U) / total);
  });
  ArduinoOTA.onError([](ota_error_t error) {
    Serial.printf("OTA error[%u]\n", error);
  });
}

void stopOtaSession() {
  otaActive = false;
  WiFi.setSleep(true);
  disconnectWiFi();
  drawCurrentPage();
}

bool startOtaSession() {
  if (otaActive) return true;
  if (bleEnabled) bleStop();
  if (!connectWiFiForServices()) { drawOtaPage(); return false; }
  WiFi.setSleep(false); 
  setupOtaHandlers();
  ArduinoOTA.begin();
  otaActive   = true;
  otaStartTs  = millis();
  currentPage = PAGE_OTA;
  drawOtaPage();
  return true;
}
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
void loop() {
  int32_t delta = 0;
  portENTER_CRITICAL(&encoderMux);
   delta = encoderDelta;
  encoderDelta = 0;
  portEXIT_CRITICAL(&encoderMux);

  if (delta != 0) {
    encoderAccum += delta;
    while (encoderAccum >= 4)  { handleEncoderStep(1);  encoderAccum -= 4; lastActivityMs = millis(); }
    while (encoderAccum <= -4) { handleEncoderStep(-1); encoderAccum += 4; lastActivityMs = millis(); }
  }

  static bool btnDown    = false;
  static unsigned long btnDownTs = 0;
  int btn = digitalRead(ENC_BTN_PIN);
  if (btn == LOW && !btnDown)   { btnDown = true; btnDownTs = millis(); }
  else if (btn == HIGH && btnDown) {
    btnDown = false;
    unsigned long held = millis() - btnDownTs;
    if (held >= 50 && held < 800) handleShortPress();
    else if (held >= 800)         handleLongPress();
  }

  if (bleEnabled && (millis() - bleEnableTs > BLE_ENABLE_TIMEOUT_MS)) bleStop();

  if (otaActive) {
    ArduinoOTA.handle();
    if (millis() - otaStartTs > OTA_ENABLE_TIMEOUT_MS) stopOtaSession();
  }

  autoAdjustLight();

  if (currentPage == PAGE_DASHBOARD && millis() - lastDashboardRefreshMs > 60000UL) drawDashboard();
  if (currentPage == PAGE_SYSTEM    && millis() - lastSystemRefreshMs    > 60000UL) drawSystem();
  if (currentPage == PAGE_OTA       && millis() - lastOtaRefreshMs       > 30000UL) drawOtaPage();

  if (!bleEnabled && !otaActive) {
    if (millis() - lastActivityMs > INACTIVITY_MIN * 60UL * 1000UL) {
      drawDashboard();
      delay(200);
      goToDeepSleep();
    }
  }

  delay(20);
}

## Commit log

2026-01-06 Added completed BOM
    [E-Ink Project BOM - Bill of Materials.csv]
2026-01-06 CAD STEP file
2026-01-09 Added CAD photos
2026-01-12 Rename Screenshot 2026-01-07 212642.png to Progress Photos/ESP32
2026-01-12 Rename light-aware-eink.pdf to E-Ink Wiring Schematic
2026-01-12 CAD photo
2026-01-12 Rename Screenshot 2026-01-08 100210.png to CAD Photos/Top View
2026-03-08 Rename E-Ink Wiring Schematic to E-Ink Wiring Schematic.pdf
2026-03-08 Rename E-ink project STEP File.step to CAD Files /EE-ink project STEP File.step
    [E-ink project STEP File.step, EE-ink project STEP File.step]
2026-03-08 Added .f3z file to CAD files folder
    [E-ink project.f3z]
2026-03-08 Create CAD file Link
2026-03-11 Rename EInkSchematic.pdf to Schematic Files/EInkSchematic.pdf
2026-05-16 updated driver (wrong color reader)
    [main.ino]
2026-05-22 Fix ADC pin attenuation setup
    [main.ino]
2026-06-18 major physical chanegs especially with encoder
